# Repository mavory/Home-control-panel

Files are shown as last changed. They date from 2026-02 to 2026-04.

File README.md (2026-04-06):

# Home-control-panel
With the ESP32-C3 you can control your smart home and other things, all wirelessly!



## Why did I do this?

I was thinking about what project to do and I came up with this, I mainly wanted to create it because I needed some kind of device to control my smart home.

## Features

- 4 touch buttons
- OLED display as an indicator of e.g. time
- Rechargeable battery for carrying
- Wireless compatibility

## Wiring Diagram



## Scripts

The script is designed for ESP32-C3 and is just a simple script, so just upload it, adjust the names, API,... and you're done!

### How it works?

When you charge the battery, you turn on the system by holding down the 1st button (as far away from the OLED as possible) and the system will connect to the network and other peripherals. Then you just need to press the buttons and, for example, your light will turn on/off.

### Libraries:

```
Arduino.h
WiFi.h
WebServer.h
WiFiClientSecure.h
Update.h
Preferences.h
Wire.h
WiFiUDP.h
time.h
esp_task_wdt.h
SinricPro.h
SinricProLight.h
SinricProSwitch.h
PubSubClient.h
ArduinoJson.h
U8g2lib.h
NTPClient.h

```

## 3D models

Here is a view of the top and bottom of the case:

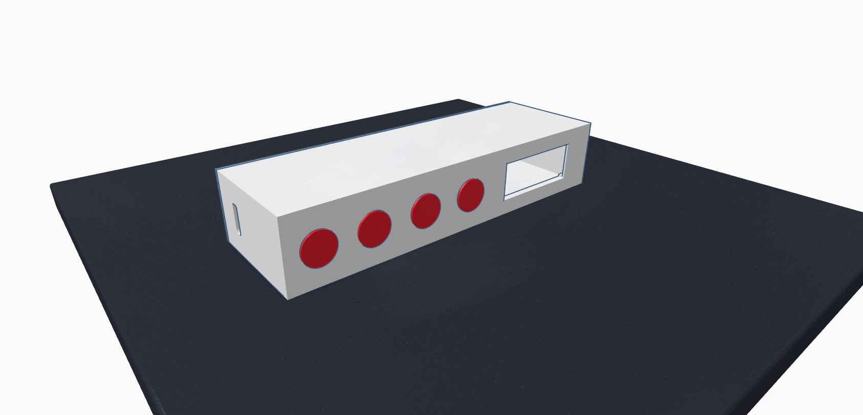
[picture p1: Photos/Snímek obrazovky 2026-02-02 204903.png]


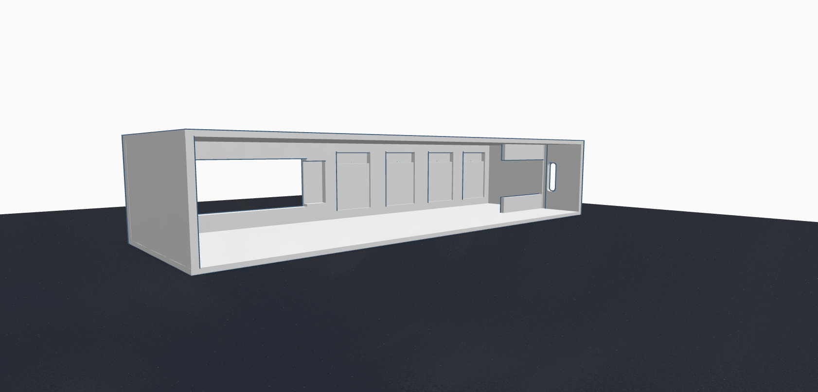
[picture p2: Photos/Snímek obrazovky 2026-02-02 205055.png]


## Bill of Materials (BOM)

| Item | Quantity | Price | Link |
| :--- | :---: | :--- | :--- |
| **ESP32-C3 Super Mini** | 1 | $7.17 | [Laskakit](https://www.laskakit.cz/esp32-c3-super-mini-wifi-bluetooth-modul/) |
| **OLED display** | 1 | $3.05 | [AliExpress](https://www.aliexpress.com/item/1005006913366977.html) |
| **Touch buttons (TTP223)** | 4 | $1.21 | [Laskakit](https://www.laskakit.cz/arduino-kapacitni-dotykove-tlacitko-ttp223/) |
| **Wires (10cm, 20pcs)** | 1 | $2.71 | [Laskakit](https://www.laskakit.cz/propojovaci-vodice-10cm-20-kusu/) |
| **Battery Li-ion 18650** | 1 | $7.66 | [Laskakit](https://www.laskakit.cz/geb-li-ion-baterie-18650-3200mah-3-7v/) |
| **Charger module / Boost converter** | 1 | $1.36 | [Laskakit](https://www.laskakit.cz/mikro-nabijecka-boost-pro-usb-powerbank-5v--usb-c/) |
| *Shipping to CZ* | - | $3.49 | - |
| **Total** | | **$26.55** | |

YouTube video: https://youtu.be/Ri25laBwVCU?is=MO4A-QQl9mjVX3hu

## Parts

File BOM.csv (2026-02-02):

Item | Quantity | Price | Link
ESP32-C3 | 1 | $7,17 | https://www.laskakit.cz/esp32-c3-super-mini-wifi-bluetooth-modul/
OLED display | 1 | $3,05 | https://www.aliexpress.com/item/1005006913366977.html?scm_id=1007.40050.354490.0&scm-url=1007.40050.354490.0
Touch buttons | 4 | $1,21 | https://www.laskakit.cz/arduino-kapacitni-dotykove-tlacitko-ttp223/
Wires | 1 | $2,71 | https://www.laskakit.cz/propojovaci-vodice-10cm-20-kusu/
Battery | 1 | $7,66 | https://www.laskakit.cz/geb-li-ion-baterie-18650-3200mah-3-7v/
Charger module | 1 | $1,36 | https://www.laskakit.cz/mikro-nabijecka-boost-pro-usb-powerbank-5v--usb-c/
Shipping to CZ |  | $3,49
Total: |  | $26,55

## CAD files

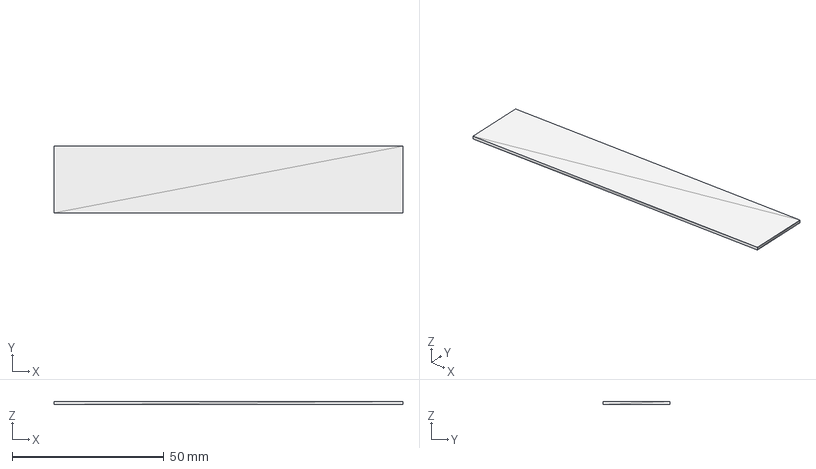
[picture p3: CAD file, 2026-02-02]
CAD/Cover.step
115.0 x 22.0 x 1.00 mm

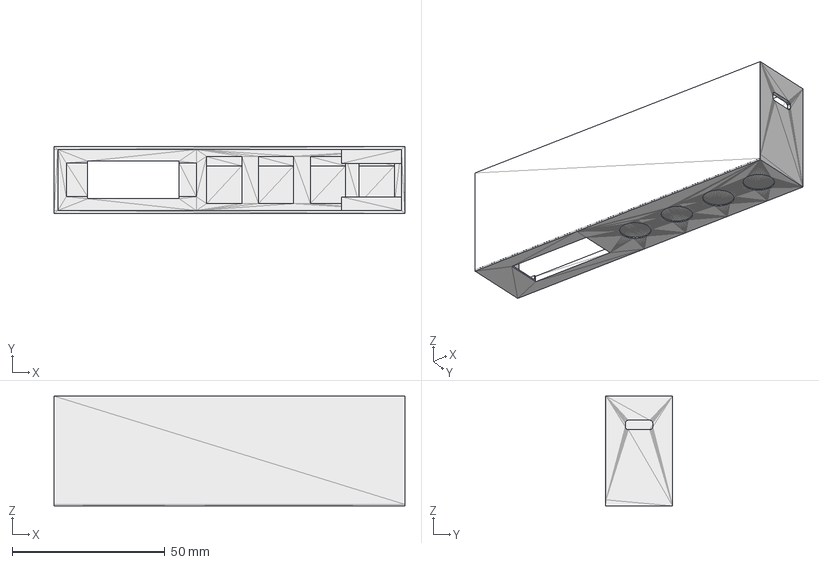
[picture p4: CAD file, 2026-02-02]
CAD/Base.step
115.0 x 22.0 x 36.0 mm

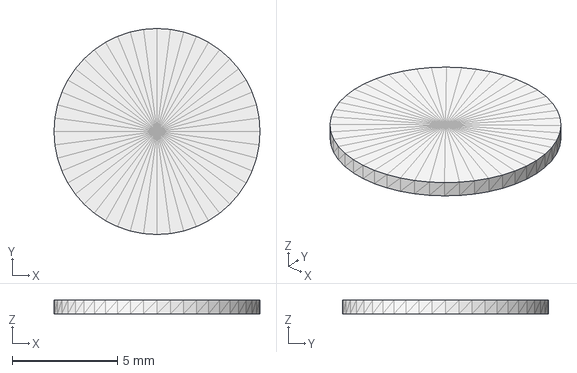
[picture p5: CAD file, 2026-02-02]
CAD/Ring.step
9.80 x 9.80 x 0.65 mm

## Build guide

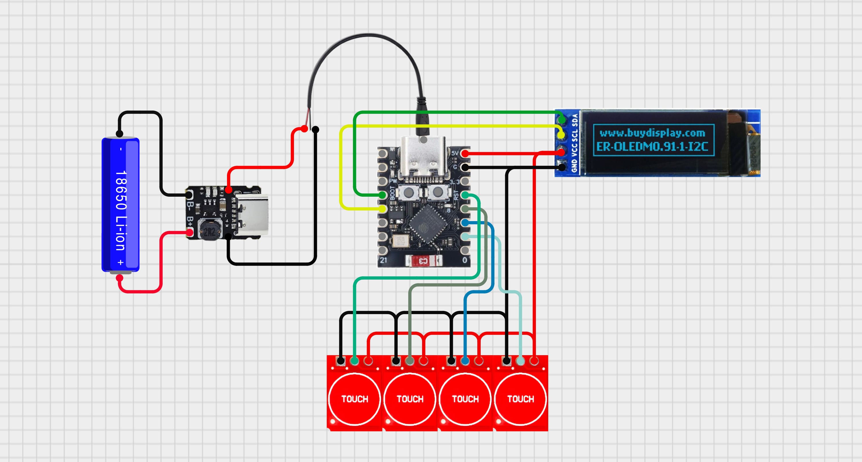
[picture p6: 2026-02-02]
Wiring diagram/circuit_image (2).png

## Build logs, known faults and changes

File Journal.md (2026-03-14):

2/2/2026 5:51 PM - The birth of the project
Time spent: 0.5h
I was thinking about how I could improve my smart home and it occurred to me that I could create a box that I could control e.g. lights, Spotify, Netflix,...
So I thought that if I put together a small ESP32-C3 and other things, I could create a portable box that would have a built-in battery!
I continued and started looking for what I had at home... I only found an OLED display and nothing else, so I had to go to the internet, where I found all the things!


2/2/2026 5:55 PM - The beginning of 3D modeling
Time spent: 0.7h
When I had it ready, I prepared all the things and started looking for their sizes etc. It went well at first and then it got even better.
Then I went to TinkerCad where I decided to model the case and I started! I immediately created the walls and then made holes for the buttons, OLED display,...
Snímek obrazovky 2026-02-02 164954

2/2/2026 5:58 PM - Continuation and a minor mistake...
Time spent: 1.1h
Right after finishing the main parts, I started making the holder for the charging module, the hole for the rings, the lid or even the rings themselves (so that I would know where each button was later)!
It went pretty quickly, but I had a small problem... If I wanted to put a battery in there, I made a case that was too small - so I took everything apart again and made smaller walls and enlarged the hole for the components.
Snímek obrazovky 2026-02-02 172511

2/2/2026 7:02 PM - Wiring diagram
Time spent: 1.0h
When I had the 3D models ready, I moved on again! I went to make a wiring diagram so that everything could be seen clearly...
First I looked for all the components, but for example the charging module was missing, so we had to create it, add pins to it,...
It was fast and in about an hour with a few mistakes I had it finished.
circuit_image (2)

2/2/2026 7:50 PM - Codinggggg
Time spent: 1.2h
I threw myself into writing code but I had one big PROBLEM! I had to figure out how to wirelessly connect Google Home to ESP32...
I did some research and found Sinric.pro, which should work great for my project.
It can turn things on and off, it can also trigger routines, etc. So I started writing and defined my code:

= Monitor strip

= Plug

= BambuLab

= BambuLab homing


2/2/2026 8 PM - BOM and GitHub editing
Time spent: 0.5h
When I had some free time, I started creating BOM and other things for GitHub!
I had to find exactly the things for my project and I did it... I also created a REPO and converted the **.**STL files to .STEP.


2/2/2026 9:26 PM - 3D rendering
Time spent: 0.7h
Lastly, I created a render where you can see how the parts fit into the holes and it fits.
I searched for a touch sensor on the internet for a while and couldn't find it, so I searched under the exact name and finally found it!!

2/2/2026 9:30 PM - Home control panel
Time spent: 0.9h
With the ESP32-C3 you can control your smart home and other things, all wirelessly!

Why did I do this?
I was thinking about what project to do and I came up with this, I mainly wanted to create it because I needed some kind of device to control my smart home.
Features
4 touch buttons
OLED display as an indicator of e.g. time
Rechargeable battery for carrying
Wireless compatibility
Wiring Diagram

Scripts
The script is designed for ESP32-C3 and is just a simple script, so just upload it, adjust the names, API,... and you're done!
How it works?
When you charge the battery, you turn on the system by holding down the 1st button (as far away from the OLED as possible) and the system will connect to the network and other peripherals. Then you just need to press the buttons and, for example, your light will turn on/off.
Libraries:
```
WiFi.h
SinricPro.h
SinricProSwitch.h
Wire.h
Adafruit_GFX.h
Adafruit_SSD1306.h
WiFiUdp.h
NTPClient.h
```

3D models
Here is a view of the top and bottom of the case:


Bill of Materials (BOM)
Item	Quantity	Price	Link
ESP32-C3 Super Mini	1	$7.17	Laskakit
OLED display	1	$3.05	AliExpress
Touch buttons (TTP223)	4	$1.21	Laskakit
Wires (10cm, 20pcs)	1	$2.71	Laskakit
Battery Li-ion 18650	1	$7.66	Laskakit
Charger module / Boost converter	1	$1.36	Laskakit
Shipping to CZ	-	$3.49	-
Total		$26.55	

3/14/2026 12:07 AM - Beginning with an error
Time spent: 3.2h
After a long time, a package with components arrived and I could start finishing my project!
1000025877 (1)
I said to myself that I would go for it and started working on the 1st part, where I had prepared and unpacked everything first! Then I just prepared a place for soldering and started soldering the first things that were needed.

But before I started soldering everything, I wanted to test if the ESP32-C3 was working at all... It was on but not showing up on my PC. So unfortunately I had to scrap my plans and start fixing the ESP.
It took me a long time to find the cause and then I looked for help on the internet forums - I used a program called "Zadig" which rewrote the port so it would show up properly and I could program it via the Arduino IDE!
Snímek obrazovky 2026-02-25 183338

3/14/2026 12:24 AM - Soldering!!
Time spent: 1.9h
After a minor mistake, I came to my senses and started doing something serious! So I took all the buttons and gradually had to fit each one with a cable and then connect all the GND and VCC so that only 1 cable was created from them. The worst thing was when my cables kept falling apart and I couldn't take it anymore...

Immediately after that I continued soldering the battery, where I had to be careful about the temperature... I managed it well! When I had it connected to the cables, I wrapped it with tape to prevent a short circuit in the box and the cable from getting caught.
Next, I took the charging module and everything went quite well...

Except for one small thing - it seemed that when I wanted to test if it was charging, the charging module kept showing me that the device was drawing power even though I had nothing connected.
So I decided to use my old charging module, which I had for a long time and I must say that it works very well!


3/14/2026 3 PM - Assembling components into a case
Time spent: 2.5h
FAHHHHH.....
I had everything I needed ready and soldered all the cables to the ESP32. It went quickly, but many times the cables came loose from the holes, so I kept having to put it back together... When something fell off, I soldered it even more tightly, then another cable fell off and I thought it was just a hallucination - but it wasn't, so I took the tin and soldered everything tightly to make it hold.
So I started gluing things into place right after that and it went very well! I accidentally glued my finger in place a few times, but after a while I had it done. The OLED display fit into place very well and I was happy about that!

Furthermore, I didn't know how to put it all together at all and I thought for a long time how to do it. First, I experimented with putting the battery on top and the ESP32 below it, but as I found out, the small integrated antenna couldn't handle it and the WiFi didn't work. It took me a long time to solve this case because I didn't know it would cause such a problem.

So I continued with the idea that I would put the battery on the bottom, spread the cables all over the case and the ESP32 would go on top. Hopefully it will work....

3/14/2026 4:10 PM - My first test!!!
Time spent: 0.8h
I was excited, so I quickly ran closer to the WiFi to test if the system would connect! And suddenly I plugged in the cable and everything worked fine. I was happy that the buttons were recognized well and when I plugged the battery into the adapter, it charged (YAYYYY).
The display lit up, but the WiFi didn't connect very well and I said to myself that I'll have to redo the whole code from scratch because it's terrible for now and I'll probably change it overall, if only it would work.
1000026028 (1)
When I put it back, some cables "unexpectedly" broke off again and I had to take out my soldering iron again and solder it carefully... But I had it finished in a few minutes and I could continue!


3/14/2026 4:53 PM - Case completion
Time spent: 1.1h
I told myself that if it works for me, I'll glue it and upload the code online via .bin! I had the quick transfer code ready and I was able to upload it before closing. It went well and I took the glue in my hand and glued the 2 parts together.
It was tedious, because when I glued it somewhere, it came off somewhere again, so it took longer than I expected. I also couldn't avoid sticky fingers... Then I sanded the case to clean it of the glue that came off my 3D case and that was it for now.


3/14/2026 7:23 PM - Codinggggg
Time spent: 1.8h
At first I thought it would be fun to code it, but after a while I still didn't know how to make the code work, but to connect to the Bambu printer and other things. So I wrote the basics, which also took me a long time. Sometimes the WiFi simply wouldn't load at all, or for example the buttons weren't recognized when I pressed them 3 times, etc.

So I already had the basics, and I also added an improvement - monitoring the information from the printer on the OLED display, so I wouldn't have to go to the printer screen all the time.
Everything worked very well, but I had to do a few things that were important for my code, because I was already at the stage where I couldn't solve the bugs, so I asked for help and the code is now working beautifully!!!


3/14/2026 7:36 PM - Testing and completion
Time spent: 2.5h

After a long time and high cortisol because of everything, I finished my project and went to try everything!! I thought it would be best if I tried everything at once and I started with the printer - it worked perfectly and then I also tried the device controlled via Sinric and everything worked perfectly. Only sjem sometimes had problems with WiFi, but that was to be expected, because sjem had almost no antenna and everything was still in the box.
Snímek obrazovky 2026-03-14 192722
Website completion
I forgot to finish the website so I could control everything and change settings through it. So I had that done in about a couple of hours and I did it in my favorite black and white theme! I also added the ability to upload new code (I already had all these things in the old one, so I just added it and didn't have to code it from scratch) and it was done.
Snímek obrazovky 2026-03-14 193538

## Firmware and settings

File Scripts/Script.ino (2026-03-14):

//WIFI AND SOMETHING ELSE
#define WIFI_SSID   ""           // WIFI
#define WIFI_PASS   ""     // PASS
#define TZ_OFFSET   3600             // CET=3600, CEST=7200!!

// I2C pro displej
#define I2C_SDA     8
#define I2C_SCL     9

//nesahat!!
#include <Arduino.h>
#include <WiFi.h>
#include <WebServer.h>
#include <WiFiClientSecure.h>
#include <Update.h>
#include <Preferences.h>
#include <Wire.h>
#include <WiFiUDP.h>
#include <time.h>
#include <esp_task_wdt.h>   

#include <SinricPro.h>
#include <SinricProLight.h>
#include <SinricProSwitch.h>
#include <PubSubClient.h>
#include <ArduinoJson.h>
#include <U8g2lib.h>
#include <NTPClient.h>

struct Config {
  char  wifi_ssid[64]          = ""; //!! add this !! very scary
  char  wifi_pass[64]          = "";
  char  sinric_key[64]         = "";
  char  sinric_secret[128]     = "";
  char  sinric_light_id[64]    = "";
  char  sinric_plug_id[64]     = "";
  char  bambu_ip[32]           = "";
  char  bambu_serial[32]       = "";
  char  bambu_code[32]         = "";
  unsigned long dbl_ms[4]      = {600, 600, 600, 600}; // 1,2,3,4x
  uint8_t  disp_brightness     = 200;
  bool     disp_on             = true;
  uint8_t  time_fmt            = 1;
  uint16_t plug_timer_min      = 5;
  int32_t  tz_offset           = TZ_OFFSET;
};

struct LogEntry {
  uint32_t ts;
  char     txt[88];
};

struct BtnState {
  bool          lastRaw    = LOW;
  bool          lastStable = LOW;
  unsigned long debounceT  = 0;
  unsigned long firstT     = 0;
  unsigned long pressStart = 0;
  int           pend       = 0;
  bool          waiting    = false;
  bool          holdFired  = false;
};

//sleeepp
bool     systemSleeping  = false;
bool     webStarted      = false;
bool     printScreenLocked = false;

// wifi stav
volatile bool wifiConnected    = false;
unsigned long wifiReconnectAt  = 0;   // recconect
int           wifiBackoffSec   = 5;   // exponenciální backoff: 5--10----20----30-----
unsigned long wifiConnectedAt  = 0;   // kdy jsme se naposledy připojili

//proměny
Config    cfg;
Preferences prefs;

// Hardware
const int      BTN_PINS[4]    = {2, 3, 4, 1};
U8G2_SSD1306_128X32_UNIVISION_F_HW_I2C u8g2(U8G2_R0, U8X8_PIN_NONE);
WebServer      server(80);

// Stav 
bool           lightOn        = false;
int            lightColorIdx  = 0;
bool           plugOn         = false;
bool           plugTimer      = false;
unsigned long  plugTimerEnd   = 0;
bool           lightTimer     = false;   // 2× BTN1 
unsigned long  lightTimerEnd  = 0;
bool           bambuLight     = false;
int            bambuSpeed     = 2;
float          bambuNozzle       = 0.0f;
float          bambuBed          = 0.0f;
float          bambuNozzleTarget = 0.0f;   // cílová teplota trysky (z Bambu MQTT)
float          bambuBedTarget    = 0.0f;   // cílová teplota podložky
int            bambuPct       = 0;
bool           bambuOnline    = false;
bool           bambuHoming    = false;
unsigned long  bambuHomingEnd = 0;
bool           bambuPrinting  = false;   // probíhá tisk????
int            bambuRemain    = 0;       // zbývající minuty
char           bambuJobName[40] = "";    // název souboru tisku
char           bambuState[16]   = "";    // IDLE/RUNNING/PAUSE/FAILED

const char* COLOR_NAMES[] = {"Bila","Cervena","Zelena","Modra","Oranzova","Fialova","Cyan"};
const uint8_t COLORS[7][3] = {
  {255,255,255},{255,0,0},{0,255,0},{0,0,255},{255,140,0},{128,0,128},{0,255,255}
};
const char* SPEED_NAMES[] = {"","Silent","Standard","Sport","Ludicrous"};

// Displej
enum DispMode { DM_TIME, DM_WAIT, DM_DONE, DM_BAMBU, DM_PRINT };
DispMode       dm    = DM_TIME;
String         dmL1  = "";
String         dmL2  = "";
unsigned long  dmExp = 0;

// Log
#define HIST_MAX 60
#define ERR_MAX  20
LogEntry  histBuf[HIST_MAX]; int histHead = 0, histCnt = 0;
LogEntry  errBuf[ERR_MAX];   int errHead  = 0, errCnt  = 0;

// Časy
WiFiUDP      ntpUDP;
NTPClient    ntpCli(ntpUDP, "pool.ntp.org");
bool         ntpSynced = false;
unsigned long bootMs   = 0;

// BambuLab
WiFiClientSecure bambuTLS;
PubSubClient     bambuMqtt(bambuTLS);
unsigned long    bambuRetry   = 0;
unsigned long    bambuLastMsg = 0;   
bool             bambuConn   = false;

// FreeRTOS
TaskHandle_t     bambuTaskHandle = NULL;
volatile bool    bambuTaskConnect = false; // spoj se!!
SemaphoreHandle_t bambuMutex = NULL;       // ochrana bambuMqtt přístupu

// Tlačítka
BtnState btn[4];
#define TOUCH_DBN_MS  8      // kapacitní sensor – kratší debounce

//deklarace nezávislosti
void saveCfg();
void loadCfg();
void addHist(const char* t);
void addErr(const char* t);
void showMsg(DispMode m, const char* l1, const char* l2 = "", unsigned long ms = 3000);
void processClick(int idx, int clicks);
void bambuConnect();
void bambuTaskStart();
void bambuSend(const char* json);
void oledBoot(const char* line1, const char* line2 = "");
void renderDisplay();
void enterSleep();
void wakeUp();
void wifiInit();
void onWiFiEvent(WiFiEvent_t event);
String buildStatus();
String buildConfig();
String buildLogStr(LogEntry* buf, int head, int cnt, int maxN);
void webSetup();
void sinricSetup();

//flash
void loadCfg() {
  prefs.begin("sr", true);
  if (prefs.getBytesLength("c") == sizeof(Config))
    prefs.getBytes("c", &cfg, sizeof(Config));
  prefs.end();
}
void saveCfg() {
  prefs.begin("sr", false);
  prefs.putBytes("c", &cfg, sizeof(Config));
  prefs.end();
  Serial.println("[CFG] Flash uložen");
}

//logy jako logy, prostě
void addHist(const char* t) {
  histBuf[histHead].ts = ntpCli.getEpochTime();
  strlcpy(histBuf[histHead].txt, t, 87);
  histHead = (histHead + 1) % HIST_MAX;
  if (histCnt < HIST_MAX) histCnt++;
  Serial.printf("[H] %s\n", t);
}
void addErr(const char* t) {
  errBuf[errHead].ts = ntpCli.getEpochTime();
  strlcpy(errBuf[errHead].txt, t, 87);
  errHead = (errHead + 1) % ERR_MAX;
  if (errCnt < ERR_MAX) errCnt++;
  Serial.printf("[E] %s\n", t);
}

//128x32 displej používáme, takže nezapomenout a taky je to OLED
void showMsg(DispMode m, const char* l1, const char* l2, unsigned long ms) {
  if (printScreenLocked && m != DM_PRINT) return; // print screen zamčen 
  dm = m; dmL1 = l1; dmL2 = l2; dmExp = millis() + ms;
}

//HANDLER,...
void onWiFiEvent(WiFiEvent_t event) {
  switch (event) {
    case ARDUINO_EVENT_WIFI_STA_GOT_IP:
      wifiConnected   = true;
      wifiConnectedAt = millis();
      wifiBackoffSec  = 5;
      Serial.printf("[WiFi] Pripojeno! IP: %s  RSSI: %d\n",
                    WiFi.localIP().toString().c_str(), WiFi.RSSI());
      if (!ntpSynced) {
        ntpCli.begin();
        ntpCli.setTimeOffset(cfg.tz_offset);
        ntpCli.update();
        if (ntpCli.getEpochTime() > 1000000) ntpSynced = true;
      }
      break;
    case ARDUINO_EVENT_WIFI_STA_DISCONNECTED:
      wifiConnected = false;
      ntpSynced     = false;
      wifiReconnectAt = millis() + (unsigned long)wifiBackoffSec * 1000UL;
      wifiBackoffSec  = min(wifiBackoffSec * 2, 30);
      Serial.printf("[WiFi] Odpojeno – reconnect za %ds\n", wifiBackoffSec / 2);
      break;
    default: break;
  }
}

void wifiInit() {
  wifiConnected  = false;
  wifiBackoffSec = 5;
  WiFi.onEvent(onWiFiEvent);
  WiFi.mode(WIFI_STA);
  WiFi.disconnect(false);
  delay(150);
  WiFi.persistent(false);
  WiFi.setAutoReconnect(false);
  WiFi.setSleep(false);
  WiFi.setTxPower(WIFI_POWER_17dBm);
  Serial.println("[WiFi] Zkousim saved creds...");
  WiFi.begin();
  unsigned long t0 = millis();
  while (!wifiConnected && millis() - t0 < 3000) delay(50);
  if (!wifiConnected) {
    Serial.printf("[WiFi] Explicitne: %s\n", cfg.wifi_ssid);
    WiFi.begin(cfg.wifi_ssid, cfg.wifi_pass);
  }
}

//OLED
static const int8_t SPIN_X[8] = { 0, 4, 5, 4, 0,-4,-5,-4};
static const int8_t SPIN_Y[8] = {-5,-4, 0, 4, 5, 4, 0,-4};
static uint8_t spinFrame = 0;


static void drawSpinner(int cx, int cy) {
  spinFrame = (spinFrame + 1) % 8;
  u8g2.drawCircle(cx, cy, 5, U8G2_DRAW_ALL);
  int hx = cx + SPIN_X[spinFrame];
  int hy = cy + SPIN_Y[spinFrame];
  u8g2.drawBox(hx - 1, hy - 1, 3, 3);
}

void oledBoot(const char* line1, const char* line2) {
  u8g2.clearBuffer();
  u8g2.drawRFrame(0, 0, 128, 32, 3);

  // ZAHLAVI
  u8g2.drawRBox(1, 1, 126, 13, 2);
  u8g2.setDrawColor(0);
  u8g2.setFont(u8g2_font_helvB08_tr);
  u8g2.drawStr((128 - u8g2.getStrWidth(line1)) / 2, 11, line1);
  u8g2.setDrawColor(1);

  // TEXT DOLE
  if (line2 && strlen(line2) > 0) {
    u8g2.setFont(u8g2_font_5x7_tr);
    u8g2.drawStr((128 - u8g2.getStrWidth(line2)) / 2, 24, line2);
  }

  //VLEVO SPINNER
  drawSpinner(10, 25);

  // Tečky pokroku vpravo dole
  uint8_t dots = (spinFrame / 2) % 4;
  for (int d = 0; d < 3; d++) {
    int bx = 108 + d * 7;
    if (d < (int)dots) u8g2.drawRBox(bx, 27, 5, 3, 1);
    else               u8g2.drawRFrame(bx, 27, 5, 3, 1);
  }

  u8g2.sendBuffer();
}

//RENDER

// WiFi RSSI 
static void drawWiFiBars(int x, int y) {
  int bars = 0;
  if (wifiConnected) {
    int r = WiFi.RSSI();
    bars = (r > -60) ? 3 : (r > -75) ? 2 : 1;
  }
  for (int b = 0; b < 3; b++) {
    int bh = 2 + b * 2;
    int bx = x + b * 5;
    int by = y - bh;
    if (b < bars) u8g2.drawBox(bx, by, 4, bh);
    else          u8g2.drawFrame(bx, by, 4, bh);
  }
}

void renderDisplay() {
  if (!cfg.disp_on) { u8g2.setPowerSave(1); return; }
  u8g2.setPowerSave(0);
  u8g2.setContrast(cfg.disp_brightness);

  // Přepínání módů
  if (printScreenLocked) {
    dm = DM_PRINT;
  } else {
    if (dm != DM_TIME && dm != DM_PRINT && millis() > dmExp) dm = DM_TIME;
    if (dm == DM_TIME  && bambuPrinting)  dm = DM_PRINT;
    if (dm == DM_PRINT && !bambuPrinting) dm = DM_TIME;
  }
  u8g2.clearBuffer();

//DALŠI VĚCI K OLED
  if (dm == DM_TIME) {

    if (!ntpSynced) {
      // Čekací obrazovka
      u8g2.drawRFrame(0, 0, 128, 32, 3);
      u8g2.setFont(u8g2_font_helvB08_tr);
      const char* msg = !wifiConnected ? "Pripojuji WiFi..." : "Sync casu...";
      u8g2.drawStr((128 - u8g2.getStrWidth(msg)) / 2, 11, msg);
      // Spinner uprostřed 
      drawSpinner(64, 24);

    } else {
      int h = ntpCli.getHours(), m = ntpCli.getMinutes(), s = ntpCli.getSeconds();

      // Status bar y=0..9
      u8g2.drawDisc(4, 4, 2, U8G2_DRAW_ALL);          // NTP dot vlevo
      if (bambuConn) u8g2.drawDisc(64, 4, 2, U8G2_DRAW_ALL); // Bambu střed
      drawWiFiBars(110, 8);                             // WiFi vpravo
      u8g2.drawHLine(0, 9, 128);                       // oddělovač

      char tb[6]; snprintf(tb, sizeof(tb), "%02d:%02d", h, m);
      u8g2.setFont(u8g2_font_logisoso20_tr);
      int tw = u8g2.getStrWidth(tb);
      int tx = 4;
      u8g2.drawStr(tx, 31, tb);

      //SE--KUNDY
      char sb[3]; snprintf(sb, sizeof(sb), "%02d", s);
      u8g2.setFont(u8g2_font_helvB08_tr);
      int secX = tx + tw + 3;
      if (secX > 103) secX = 103;                      // nepřeteče za okraj
      u8g2.drawRFrame(secX, 21, 23, 10, 2);            // box 23×10
      // Blikající tep-tečka vlevo v boxu
      if (s % 2 == 1) u8g2.drawDisc(secX + 3, 26, 1, U8G2_DRAW_ALL);
      // Čísla sekund centrovaná v boxu
      int sw = u8g2.getStrWidth(sb);
      u8g2.drawStr(secX + (23 - sw) / 2, 29, sb);
    }

  } else if (dm == DM_PRINT && bambuPrinting) {

    const char* icon = (strcmp(bambuState, "PAUSE") == 0) ? "||" : ">";
    u8g2.setFont(u8g2_font_helvB08_tr);
    u8g2.drawStr(0, 9, icon);

    char job[20] = "---";
    if (strlen(bambuJobName) > 0) {
      strlcpy(job, bambuJobName, sizeof(job));
      char* dot = strrchr(job, '.'); if (dot) *dot = '\0';
    }
    u8g2.setFont(u8g2_font_5x7_tr);
    u8g2.drawStr(12, 9, job);

    if (bambuRemain > 0) {
      char tbuf[10];
      if (bambuRemain >= 60) snprintf(tbuf, sizeof(tbuf), "%d:%02d", bambuRemain/60, bambuRemain%60);
      else                   snprintf(tbuf, sizeof(tbuf), "%dm", bambuRemain);
      u8g2.drawStr(128 - u8g2.getStrWidth(tbuf), 9, tbuf);
    }

    // Progress bar 
    u8g2.drawRFrame(0, 11, 128, 9, 2);
    int bw = (int)(bambuPct / 100.0f * 124.0f);
    if (bw > 0) u8g2.drawRBox(2, 13, bw, 5, 1);
    char pct[6]; snprintf(pct, sizeof(pct), "%d%%", bambuPct);
    u8g2.setFont(u8g2_font_5x7_tr);
    int px = (128 - u8g2.getStrWidth(pct)) / 2;
    u8g2.setDrawColor(0); u8g2.drawStr(px, 19, pct); u8g2.setDrawColor(1);
    if (bw + 2 < px + u8g2.getStrWidth(pct)) {
      u8g2.setClipWindow(bw + 2, 11, 127, 20);
      u8g2.drawStr(px, 19, pct);
      u8g2.setMaxClipWindow();
    }

    // Teploty 
    char nBuf[16], bBuf[16];
    if (bambuNozzleTarget > 5) snprintf(nBuf, sizeof(nBuf), "N:%.0f/%.0f", bambuNozzle, bambuNozzleTarget);
    else                       snprintf(nBuf, sizeof(nBuf), "N:%.0f",      bambuNozzle);
    if (bambuBedTarget > 5)    snprintf(bBuf, sizeof(bBuf), "B:%.0f/%.0f", bambuBed,    bambuBedTarget);
    else                       snprintf(bBuf, sizeof(bBuf), "B:%.0f",      bambuBed);
    u8g2.setFont(u8g2_font_helvB08_tr);
    u8g2.drawStr(0, 31, nBuf);
    u8g2.drawStr(128 - u8g2.getStrWidth(bBuf), 31, bBuf);
    u8g2.drawVLine(63, 21, 10);

  } else if (dm == DM_PRINT && !bambuPrinting) {

    u8g2.drawRFrame(0, 0, 128, 32, 3);
    u8g2.drawRBox(1, 1, 126, 13, 2);
    u8g2.setDrawColor(0);
    u8g2.setFont(u8g2_font_helvB08_tr);
    const char* ttl = "BAMBU  A1 MINI";
    u8g2.drawStr((128 - u8g2.getStrWidth(ttl)) / 2, 11, ttl);
    u8g2.setDrawColor(1);
    u8g2.drawHLine(1, 14, 126);

    u8g2.setFont(u8g2_font_helvB08_tr);
    char nL[16], bL[16];
    if (bambuNozzleTarget > 5) snprintf(nL, sizeof(nL), "N:%.0f/%.0f", bambuNozzle, bambuNozzleTarget);
    else                       snprintf(nL, sizeof(nL), "N:%.0f",      bambuNozzle);
    if (bambuBedTarget > 5)    snprintf(bL, sizeof(bL), "B:%.0f/%.0f", bambuBed,    bambuBedTarget);
    else                       snprintf(bL, sizeof(bL), "B:%.0f",      bambuBed);
    u8g2.drawStr(3, 23, nL);
    u8g2.drawStr(128 - u8g2.getStrWidth(bL) - 3, 23, bL);
    u8g2.drawVLine(63, 15, 8);

    const char* st  = (strlen(bambuState) > 0) ? bambuState : "---";
    const char* con = bambuConn ? "WiFi OK" : "Offline";
    u8g2.setFont(u8g2_font_5x7_tr);
    u8g2.drawStr(3, 31, st);
    u8g2.drawStr(128 - u8g2.getStrWidth(con) - 3, 31, con);
    u8g2.drawVLine(63, 24, 7);

  } else {
    u8g2.drawRFrame(0, 0, 128, 32, 3);
    u8g2.drawRBox(1, 1, 126, 13, 2);
    u8g2.setDrawColor(0);
    u8g2.setFont(u8g2_font_helvB08_tr);
    u8g2.drawStr((128 - u8g2.getStrWidth(dmL1.c_str())) / 2, 11, dmL1.c_str());
    u8g2.setDrawColor(1);
    if (dmL2.length() > 0) {
      u8g2.setFont(u8g2_font_helvB08_tr);
      u8g2.drawStr((128 - u8g2.getStrWidth(dmL2.c_str())) / 2, 28, dmL2.c_str());
    }
  }

  u8g2.sendBuffer();
}


//  BambuLab MQTT

void bambuCallback(char* topic, byte* payload, unsigned int len) {
  if (len > 1400) return;
  bambuLastMsg = millis(); // RESET
  char buf[1401]; memcpy(buf, payload, len); buf[len] = 0;
  StaticJsonDocument<1400> doc;
  if (deserializeJson(doc, buf) != DeserializationError::Ok) return;
  if (doc.containsKey("print")) {
    JsonObject p = doc["print"];
    if (p.containsKey("nozzle_temper"))          bambuNozzle       = p["nozzle_temper"].as<float>();
    if (p.containsKey("bed_temper"))             bambuBed          = p["bed_temper"].as<float>();
    if (p.containsKey("nozzle_target_temper"))   bambuNozzleTarget = p["nozzle_target_temper"].as<float>();
    if (p.containsKey("bed_target_temper"))      bambuBedTarget    = p["bed_target_temper"].as<float>();
    if (p.containsKey("mc_percent"))             bambuPct          = p["mc_percent"].as<int>();
    if (p.containsKey("mc_remaining_time")) bambuRemain = p["mc_remaining_time"].as<int>();

    // Název tiskového jobu
    if (p.containsKey("subtask_name")) {
      const char* jn = p["subtask_name"];
      if (jn && strlen(jn) > 0) strlcpy(bambuJobName, jn, sizeof(bambuJobName));
    }

    // Stav tisku – rozhoduje co zobrazit na OLED
    if (p.containsKey("gcode_state")) {
      const char* gs = p["gcode_state"];
      strlcpy(bambuState, gs ? gs : "", sizeof(bambuState));

      bool wasPrinting = bambuPrinting;
      bambuPrinting = (strcmp(bambuState, "RUNNING") == 0 ||
                       strcmp(bambuState, "PAUSE")   == 0);

      // Homing hotov
      if (strcmp(bambuState, "IDLE") == 0 && bambuHoming) {
        bambuHoming = false;
        addHist("Bambu: homing hotov");
      }
      // Automaticky přepni na print screen při startu tisku
      if (bambuPrinting && !wasPrinting) {
        char h[60]; snprintf(h, sizeof(h), "Tisk zahajen: %s", bambuJobName);
        addHist(h);
        dm = DM_PRINT; // automaticky zobraz progress
      }
      // Tisk skončil 
      if (!bambuPrinting && wasPrinting) {
        dm = DM_TIME;
        addHist("Tisk dokoncen");
      }
    }
  }
  bambuOnline = true;
}


void bambuTask(void* param) {
  // DISK 0
  for (;;) {
    // Čekej na signál z loop()
    if (bambuTaskConnect && wifiConnected) {
      bambuTaskConnect = false;

      if (xSemaphoreTake(bambuMutex, pdMS_TO_TICKS(200)) == pdTRUE) {
        Serial.println("[Bambu] Task: TLS connect...");
        bambuTLS.setInsecure();
        bambuTLS.setHandshakeTimeout(10);
        bambuMqtt.setServer(cfg.bambu_ip, 8883);
        bambuMqtt.setCallback(bambuCallback);
        bambuMqtt.setBufferSize(2048);
        bambuMqtt.setKeepAlive(60);   // 60s keepalive – zabrání timeoutům
        bambuMqtt.setSocketTimeout(5); // 5s socket timeout
        String cid = "sr_" + String(cfg.bambu_serial);

        if (bambuMqtt.connect(cid.c_str(), "bblp", cfg.bambu_code)) {
          char sub[80];
          snprintf(sub, sizeof(sub), "device/%s/report", cfg.bambu_serial);
          bambuMqtt.subscribe(sub);
          bambuConn    = true;
          bambuLastMsg = millis();
          Serial.println("[Bambu] Task: Pripojeno!");
          addHist("BambuLab: pripojeno");
        } else {
          Serial.printf("[Bambu] Task: Selhalo, stav %d\n", bambuMqtt.state());
          bambuConn = false;
        }
        xSemaphoreGive(bambuMutex);
      }
    }

    // Udržuj MQTT alive
    if (bambuMqtt.connected()) {
      if (xSemaphoreTake(bambuMutex, pdMS_TO_TICKS(10)) == pdTRUE) {
        bambuMqtt.loop();
        xSemaphoreGive(bambuMutex);
      }
    } else if (bambuConn) {
      // PubSubClient hlásí odpojení – aktualizuj flag
      bambuConn = false;
      Serial.println("[Bambu] Task: Detekováno odpojení");
    }

    vTaskDelay(pdMS_TO_TICKS(10)); //10 mS
  }
}

void bambuTaskStart() {
  bambuMutex = xSemaphoreCreateMutex();
  xTaskCreatePinnedToCore(
    bambuTask,        // funkce
    "BambuTask",      // název
    8192,             // stack 
    NULL,             // parametr
    1,                // priorita
    &bambuTaskHandle, // handle
    0                 // core 0 
  );
  Serial.println("[Bambu] Task spusten na core 0");
}

void bambuConnect() {
  // Pouze nastav příznak 
  if (strlen(cfg.bambu_ip) < 4) return;
  bambuTaskConnect = true;
}
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
void loop() {
  unsigned long now = millis();

  // Watchdog – VŽDY první
  esp_task_wdt_reset();

  // reccpnect
  if (!systemSleeping && !wifiConnected && now >= wifiReconnectAt && wifiReconnectAt > 0) {
    Serial.println("[WiFi] Reconnect pokus...");
    wifiReconnectAt = 0;
    WiFi.disconnect(false);
    delay(50);
    WiFi.begin(cfg.wifi_ssid, cfg.wifi_pass);
  }

  // web
  if (!systemSleeping && webStarted) {
    server.handleClient();
    server.handleClient();
  }

  // ④ SinricPro (jen pokud WiFi OK)
  if (!systemSleeping && wifiConnected) SinricPro.handle();

  // bambu
  if (!systemSleeping && wifiConnected) {
    unsigned long now2 = millis();
    bool stale = bambuConn && bambuLastMsg > 0 && (now2 - bambuLastMsg) > 180000UL; // 3 min bez zprávy
    bool disconnected = !bambuMqtt.connected() && !bambuTaskConnect;

    if ((disconnected || stale) && (now2 - bambuRetry) > 20000 && strlen(cfg.bambu_ip) > 4) {
      if (stale) {
        Serial.println("[Bambu] Stale connection – force reconnect");
        bambuMqtt.disconnect();
      }
      bambuRetry       = now2;
      bambuConn        = false;
      bambuOnline      = false;
      bambuTaskConnect = true;
    }
  }

//ntp
  static unsigned long ntpLast = 0;
  if (!systemSleeping && wifiConnected) {
    unsigned long ntpInterval = ntpSynced ? 300000UL : 10000UL;
    if (now - ntpLast > ntpInterval) {
      ntpLast = now;
      if (ntpCli.update()) {
        if (!ntpSynced) Serial.println("[NTP] Cas synced!");
        ntpSynced = true;
      }
    }
  }

  // homing
  if (bambuHoming && now > bambuHomingEnd) bambuHoming = false;

  //plug
  if (!systemSleeping && plugTimer && now > plugTimerEnd) {
    plugTimer = false; plugOn = false;
    SinricProSwitch& P = SinricPro[cfg.sinric_plug_id];
    P.sendPowerStateEvent(false);
    addHist("Zasuvka timer: VYP");
    showMsg(DM_DONE, "Timer", "Zasuvka VYP");
  }

  // light
  if (!systemSleeping && lightTimer && now > lightTimerEnd) {
    lightTimer = false; lightOn = false;
    SinricProLight& L = SinricPro[cfg.sinric_light_id];
    L.sendPowerStateEvent(false);
    addHist("Svetlo timer: VYP");
    showMsg(DM_DONE, "Svetlo timer", "VYPNUTO");
  }

  // sleeeeeeeeeeeeeeeeeeeeeeeeeeeeeeeeep
  if (!systemSleeping && btn[0].lastStable && !btn[0].holdFired) {
    unsigned long held = now - btn[0].pressStart;
    if (held >= 1000 && held < LONG_PRESS_MS) {
      int secs = (int)((LONG_PRESS_MS - held) / 1000) + 1;
      char cd[20]; snprintf(cd, sizeof(cd), "Usnu za %ds...", secs);
      showMsg(DM_WAIT, "Drz BTN1", cd, 300);
    }
  }

  // buttons
  handleBtns();

  // display
  static unsigned long dispLast = 0;
  if (!systemSleeping && now - dispLast > 50) {
    dispLast = now;
    renderDisplay();
  }
}

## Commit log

2026-02-02 Wiring diagram
2026-02-02 .STEP files
    [Base.step, Cover.step, Ring.step]
2026-02-02 README.md
    Added a Bill of Materials (BOM) section with item details.
2026-02-02 Journal.md
    Documented the progress and key milestones of the smart home project, including 3D modeling, wiring diagrams, and coding efforts.
2026-02-02 README.md
    Added project overview, features, wiring diagram, scripts, libraries, 3D models, and BOM.
2026-03-14 Revise journal entries for project progress
    Updated journal entries with detailed project progress, including 3D modeling, wiring diagrams, coding, and testing phases. Added images and improved formatting for clarity.
